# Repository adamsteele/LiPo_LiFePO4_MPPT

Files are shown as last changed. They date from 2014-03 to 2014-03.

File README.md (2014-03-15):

LiPo LiFePO4 MPPT
=================

This is a basic MPPT charger currently setup to do 3S LiPo batteries based on the LT3652 chip.

This is mostly a copy of this http://www.mictronics.de/projects/solar-cell-mppt/ project. It just didn't have nice eagle schematics or a completed BOM.

I've built and tested this board and it mostly works. What didn't work for me are the status LEDs, I haven't figured out why.

The board should be stackable to provide a higher current rating, but I haven't tested it. Linear Electronics has some app notes on the subject that I recommend reading. The stackable boards don't need to be fully populated.

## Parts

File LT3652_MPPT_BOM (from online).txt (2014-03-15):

Digi-Key Part Number		Quantity	Description							Schematic Numbers
338-1703-ND					1			CAP ALUM 470UF 50V 20% RADIAL		C1
490-1864-1-ND				1			CAP CER 4.7UF 50V 10% X7R 1210		C2
490-1695-1-ND				1			CAP CER 1UF 10V 10% X7R 0805		C3 (don't think we need 10)
587-3152-1-ND				1			CAP CER 100UF 16V 20% X5R 1210		C4
445-1434-1-ND				1			CAP CER 10UF 25V 20% X7R 1210		C5 (replaced with 587-2599-1-ND)
445-1345-1-ND				1			CAP CER 0.022UF 100V X7R 0805		C6
475-2709-1-ND				1			LED SMARTLED GREEN 570NM 0603		D1
475-2506-1-ND				1			LED SMARTLED 630NM RED 0603 SMD		D2
MBRS340T3GOSCT-ND			1			DIODE SCHOTTKY 40V 3A SMC			D3
BZV55C10-TPMSCT-ND			1			DIODE ZENER 500MW 10V MINIMELF		D4
BZV55C4V7-TPMSCT-ND			1			DIODE ZENER 500MW 4.7V MINIMELF		D5
LL4148DICT-ND				1			DIODE SWITCH 75V 500MW MINIMELF		D7 (there is no D6)
LT3652HVEMSE#PBF-ND			1			IC BATTERY CHARGER 2A 12-MSOP		IC1 (replaced with LT3652EMSE#PBF-ND ; it's cheaper)
SI4401DDY-T1-GE3CT-ND		1			MOSFET P-CH 40V 8-SOIC				IC2
495-1796-1-ND				1			INDUCTOR POWER 10UH 3.4A SMD		L1
P510KHCT-ND					1			RES 510K OHM 1/10W 1% 0603 SMD		R1
P105KHCT-ND					1			RES 105K OHM 1/10W 1% 0603 SMD		R2
P10.0KHCT-ND				3			RES 10.0K OHM 1/10W 1% 0603 SMD		R3 R4 R11
989-1029-1-ND				1			RES .050 OHM 0.5W 1% 1206 SMD		R5
989-1031-1-ND				1			RES .100 OHM 0.5W 1% 1206 SMD		R6
RG20P280KBCT-ND				1			RES 280K OHM 1/8W .1% 0805 SMD		R7
P28.7KDBCT-ND				1			RES 28.7K OHM 1/10W .1% 0603 SMD	R8
CRT0805-BY-1003ELFCT-ND		1			RES 100K OHM 1/8W .1% 0805 SMD		R9
P100KHCT-ND					1			RES 100K OHM 1/10W 1% 0603 SMD		R10
P107KHCT-ND					1			RES 107K OHM 1/10W 1% 0603 SMD		not used

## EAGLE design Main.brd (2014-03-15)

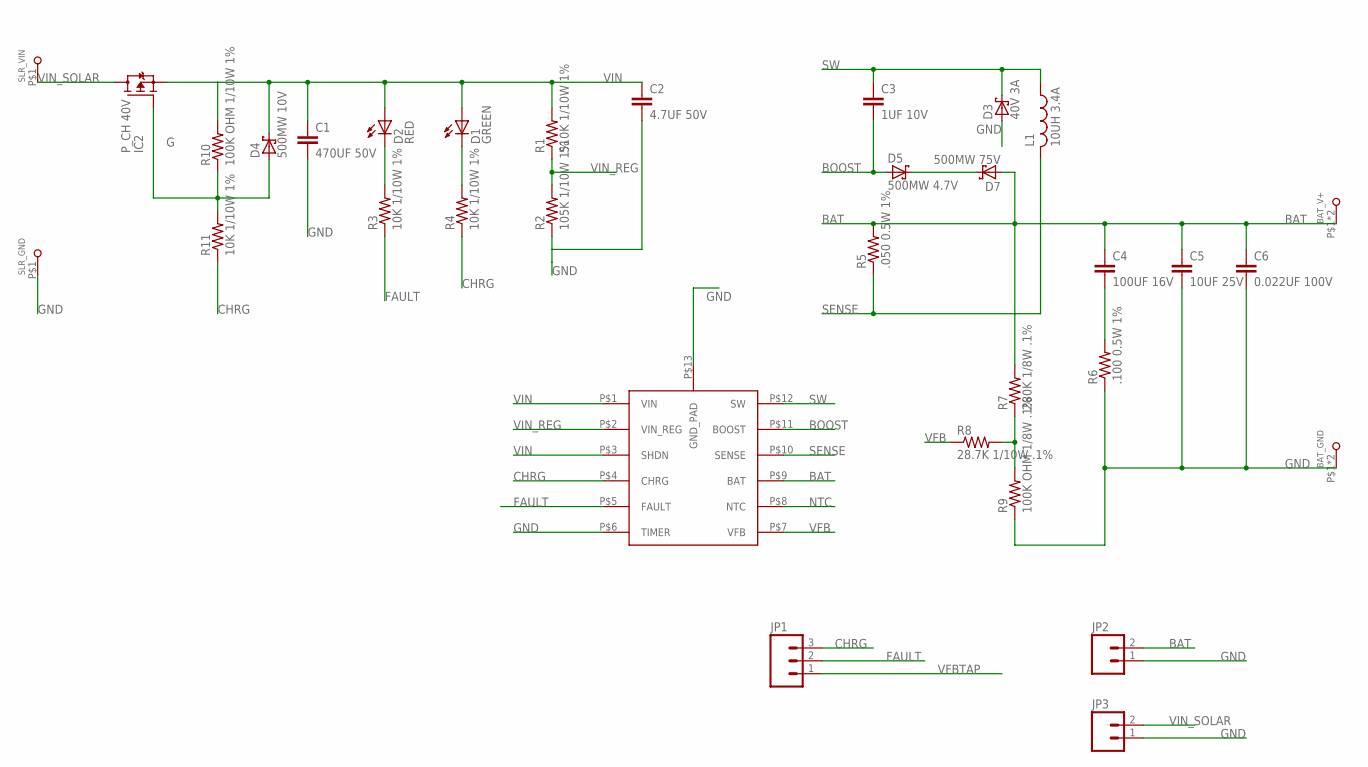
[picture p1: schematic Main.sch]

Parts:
BAT_GND: LARGE_PADMED_PAD_PAIR; MEDIUM_PAD_PAIR
BAT_V+: LARGE_PADMED_PAD_PAIR; MEDIUM_PAD_PAIR
C1: 470UF 50V; 5X5_CAP_HOLES
C2: 4.7UF 50V; C1210
C3: 1UF 10V; C0805
C4: 100UF 16V; C1210
C5: 10UF 25V; C1210
C6: 0.022UF 100V; C0805
D1: GREEN; SML0603
D2: RED; SML0603
D3: 40V 3A; SMC
D4: 500MW 10V; MINIMELF
D5: 500MW 4.7V; MINIMELF
D7: 500MW 75V; MINIMELF
IC1: LT3652MSE-12-MIGHT-BE-HAND-DOOABLE; MSE_12_HANDSOLDERABLE
IC2: P_CH 40V; SO-8_SOIC8
JP1: M03LOCK; 1X03_LOCK
JP2, JP3: M02LOCK; 1X02_LOCK
L1: 10UH 3.4A; ECOS_INDUCTOR_SMT
R1: 510K 1/10W 1%; R0603
R2: 105K 1/10W 1%; R0603
R3, R4, R11: 10K 1/10W 1%; R0603
R5: .050 0.5W 1%; R1206
R6: .100 0.5W 1%; R1206
R7: 280K 1/8W .1%; R0805
R8: 28.7K 1/10W .1%; R0603
R9: 100K OHM 1/8W .1%; R0805
R10: 100K OHM 1/10W 1%; R0603
SLR_GND: LARGE_PADMED_PAD; MEDIUM_PAD
SLR_VIN: LARGE_PADMED_PAD; MEDIUM_PAD

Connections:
BAT: BAT_V+.P$1, BAT_V+.P$2, C4.1, C5.1, C6.1, D7.P$1 (A), IC1.P$9 (BAT), JP2.2, R5.2, R7.2
BOOST: C3.2, D5.P$1 (A), IC1.P$11 (BOOST)
CHRG: IC1.P$4 (CHRG), JP1.3, R4.1, R11.1
FAULT: IC1.P$5 (FAULT), JP1.2, R3.1
G: D4.P$1 (A), IC2.4 (G), R10.1, R11.2
GND: BAT_GND.P$1, BAT_GND.P$2, C1.P$2 (2), C2.2, C5.2, C6.2, D3.A, IC1.P$6 (TIMER), IC1.P$13 (GND_PAD), JP2.1, JP3.1, R2.1, R6.1, R9.1, SLR_GND.P$1
unnamed: D5.P$2 (C), D7.P$2 (C)
unnamed: D2.C, R3.2
unnamed: D1.C, R4.2
unnamed: C4.2, R6.2
NTC: IC1.P$8 (NTC)
SENSE: IC1.P$10 (SENSE), L1.P$2 (2), R5.1
SW: C3.1, D3.C, IC1.P$12 (SW), L1.P$1 (1)
VFB: IC1.P$7 (VFB), R8.1
VFBTAP: JP1.1, R7.1, R8.2, R9.2
VIN: C1.P$1 (1), C2.1, D1.A, D2.A, D4.P$2 (C), IC1.P$1 (VIN), IC1.P$3 (SHDN), IC2.1 (S), IC2.2 (S), IC2.3 (S), R1.2, R10.2
VIN_REG: IC1.P$2 (VIN_REG), R1.1, R2.2
VIN_SOLAR: IC2.5 (D), IC2.6 (D), IC2.7 (D), IC2.8 (D), JP3.2, SLR_VIN.P$1

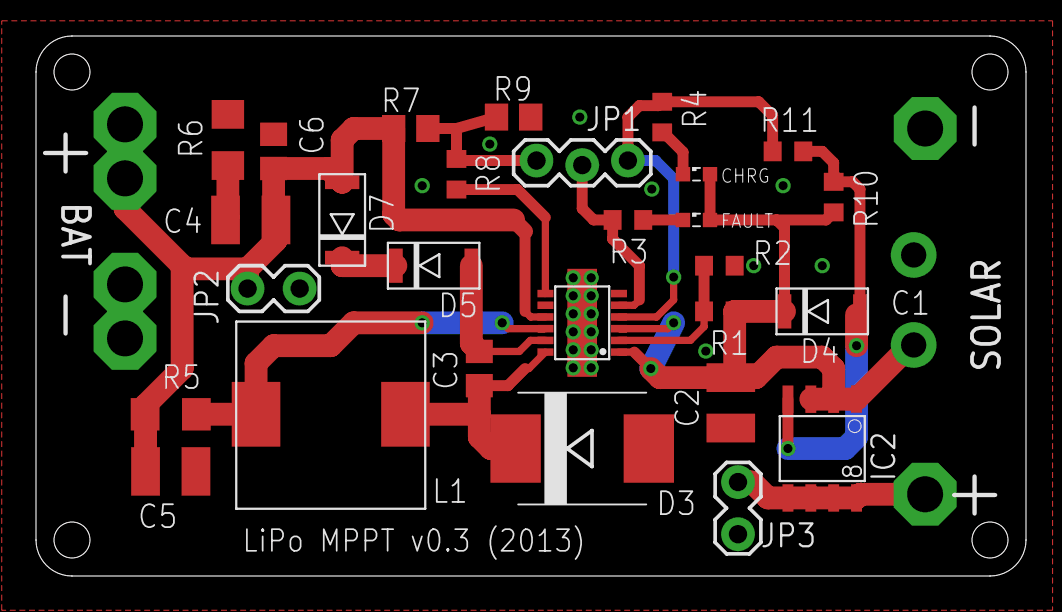
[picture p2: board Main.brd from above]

Board: 2 copper layers, 55.0 x 30.0 mm, 33 parts (0 on the bottom side), 17 nets.

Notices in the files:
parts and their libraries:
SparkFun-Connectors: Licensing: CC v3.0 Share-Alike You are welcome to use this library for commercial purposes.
